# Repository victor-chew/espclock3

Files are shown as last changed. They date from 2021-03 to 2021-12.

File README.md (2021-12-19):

# ESPCLOCK3
Internet-enabled Analog Clock using ESP8266 and ATtiny85

### Description
This is version 3 of my [ESPClock](https://www.randseq.org/2016/10/hacking-analog-clock-to-sync-with-ntp.html) project.

The clock gets accurate time information from the Internet and makes sure the physical clock time is up-to-date. It also automatically detects your current timezone via browser geolocation and deals with daylight saving adjustments with no user intervention.

V1 uses the ESP-12E development board to drive a cheap $2 Ikea analog clock.

V2 uses the WeMOS D1 Mini and ATtiny85 to reduce power draw. That design yields a runtime of ~1 month.

V3 uses the ESP-07, ATtiny85 and PCF8563 RTC to reduce the power draw even further. This design yields at least 4 months of runtime on a set of readily-available 4 x 1.2V AA NiMH rechargables.

### Links:
* [Design](https://www.randseq.org/2020/05/espclock3-final-version.html)

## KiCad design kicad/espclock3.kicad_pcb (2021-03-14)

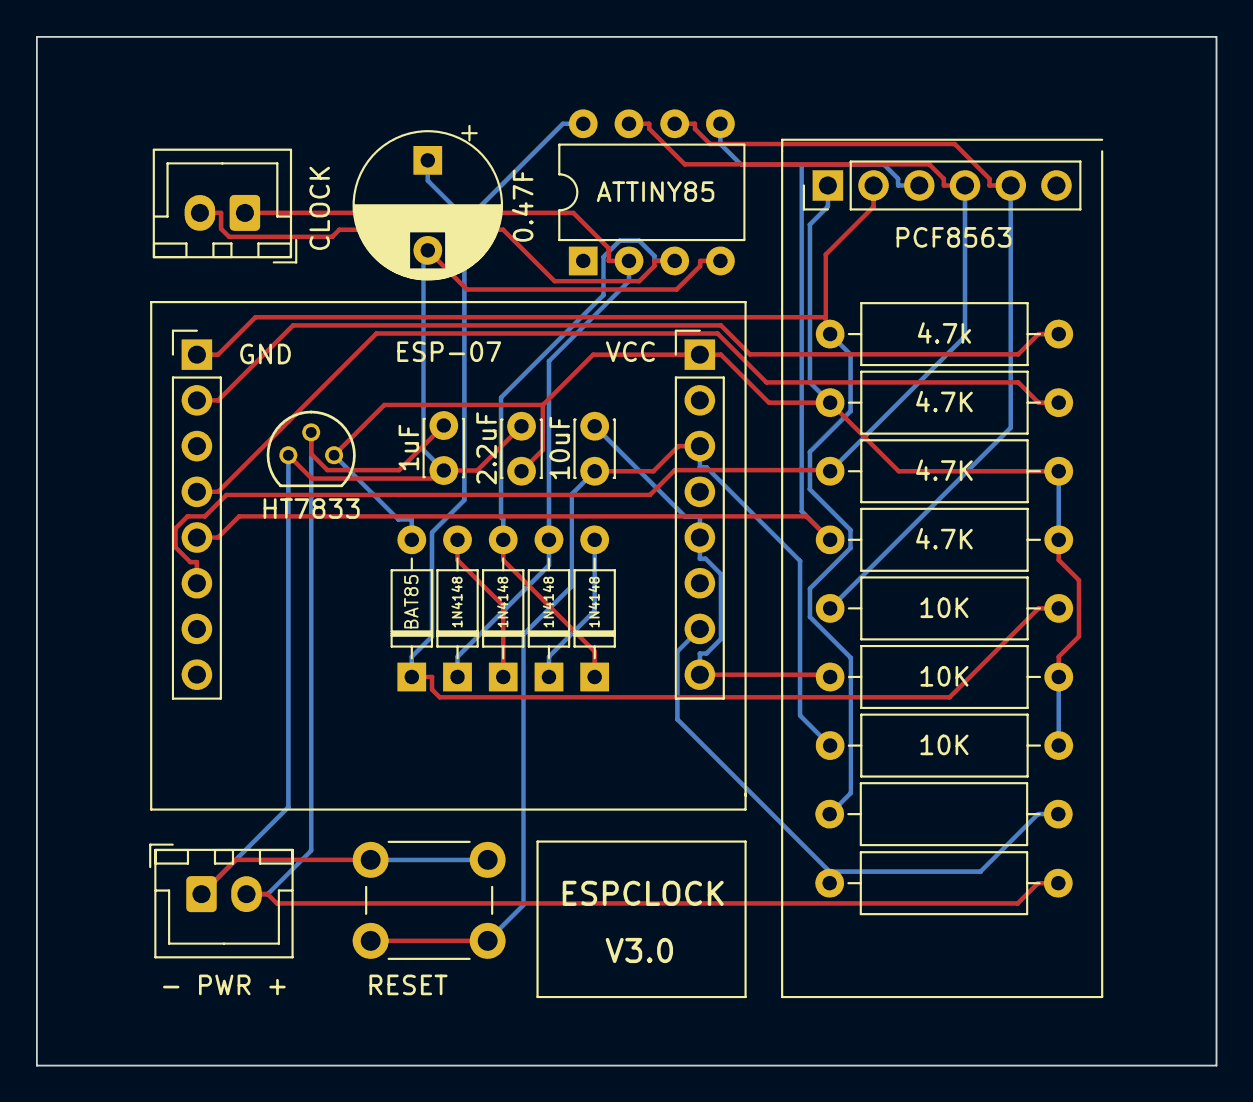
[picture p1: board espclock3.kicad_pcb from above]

Board: 2 copper layers, 65.5 x 57.2 mm, 26 parts (0 on the bottom side), 17 nets.

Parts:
C1: 1uF; C_Disc_D3.0mm_W2.0mm_P2.50mm
C2: 2.2uF; C_Disc_D3.0mm_W2.0mm_P2.50mm
C3: 10uF; C_Disc_D3.0mm_W2.0mm_P2.50mm
C4: 0.47F; CP_Radial_D8.0mm_P5.00mm
D1: BAT85; D_DO-35_SOD27_P7.62mm_Horizontal
D2, D3, D4, D5: 1N4148; D_DO-35_SOD27_P7.62mm_Horizontal
ESP07-GND1, ESP07-VCC1: Conn_01x08_Female; PinHeader_1x08_P2.54mm_Vertical
J1: Quartz Clock; JST_XH_B2B-XH-A_1x02_P2.50mm_Vertical
J2: Battery; JST_XH_B2B-XH-A_1x02_P2.50mm_Vertical
J5: PCF8563; PinHeader_1x06_P2.54mm_Vertical
L1: HT7833; ht7333-a
R1, R4, R7, R9: 10K; R_Axial_DIN0309_L9.0mm_D3.2mm_P12.70mm_Horizontal
R2: 4.7k; R_Axial_DIN0309_L9.0mm_D3.2mm_P12.70mm_Horizontal
R3, R5, R6: 4.7K; R_Axial_DIN0309_L9.0mm_D3.2mm_P12.70mm_Horizontal
R8: 47K; R_Axial_DIN0309_L9.0mm_D3.2mm_P12.70mm_Horizontal
SW1: SW_Push; SW_PUSH_6mm
U3: ATtiny85-20PU; DIP-8_W7.62mm

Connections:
/ADC: ESP07-VCC1.7, R8.1, R9.2
/COT: J5.5, R7.1, U3.6
/GND: ESP07-GND1.1, J5.2, R2.1, R9.1
/GPIO0: ESP07-GND1.4, R3.2
/GPIO12: C3.1, ESP07-VCC1.3, R4.1, SW1.2
/GPIO15: ESP07-GND1.2, R2.2
/GPIO16: C3.2, ESP07-VCC1.5, ESP07-VCC1.8, R1.1
/SCL: ESP07-GND1.6, J5.4, R5.1, U3.7
/SDA: ESP07-GND1.5, J5.3, R6.1, U3.5
/VCC: C2.1, D1.2, ESP07-VCC1.1, J5.1, L1.3, R1.2, R3.1, R4.2, R5.2, R6.2
unnamed: C1.1, J2.2, L1.2, R8.2
unnamed: C1.2, C2.2, C4.2, J2.1, L1.1, SW1.1, U3.4
unnamed: C4.1, D1.1, R7.2, U3.8
unnamed: D2.1, D3.2, J1.1, U3.2
unnamed: D2.2, D4.1
unnamed: D3.1, D5.2
unnamed: D4.2, D5.1, J1.2, U3.3

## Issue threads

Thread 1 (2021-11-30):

Question

bilogic, 2021-11-30:
Hi,

Cool project! How does your electronics figure out the hand positions? (And not lose track of them)

victor-chew, 2021-12-01:
You tell it the current hand position during setup, and it will keep track during movement of the hands. The tricky thing is to remember the hand position (by writing to EEPROM on the ATtiny85) when low power is detected.

bilogic, 2021-12-01:
Ah ok got it, thank you!
I would jump straight into this if it was more robust :)

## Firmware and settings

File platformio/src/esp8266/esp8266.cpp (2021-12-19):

/*
 * esp8266.cpp
 *
 * Copyright 2020 Victor Chew
 *
 * Licensed under the Apache License, Version 2.0 (the "License");
 * you may not use this file except in compliance with the License.
 * You may obtain a copy of the License at
 *
 *     http://www.apache.org/licenses/LICENSE-2.0
 *
 * Unless required by applicable law or agreed to in writing, software
 * distributed under the License is distributed on an "AS IS" BASIS,
 * WITHOUT WARRANTIES OR CONDITIONS OF ANY KIND, either express or implied.
 * See the License for the specific language governing permissions and
 * limitations under the License.
 */
 
#include <Arduino.h>
#include <stdint.h>
#include <LittleFS.h>
#include <ESP8266WiFi.h>
#include <DNSServer.h>
#include <ESP8266WebServer.h>
#include <WiFiManager.h>
#include <ESP8266HTTPClient.h>
#include <Rtc_Pcf8563.h> // https://github.com/elpaso/Rtc_Pcf8563

#define DEBUG
#ifdef DEBUG
#include <Syslog.h>
WiFiUDP udpClient;
Syslog syslog(udpClient, "192.168.1.167", 514, "ESPCLOCK3", "ESPCLOCK3", LOG_KERN);
#endif

void debug(const char *format, ...) {
  #ifdef DEBUG
    char buf[256];
    va_list ap;
    va_start(ap, format);
    vsnprintf(buf, sizeof(buf), format, ap);
    va_end(ap);
    syslog.log(buf);
  #endif
}

// Application Javascript to be injected into WiFiManager's config page
#define QUOTE(...) #__VA_ARGS__
const char* jscript = QUOTE(
  <script>
    document.addEventListener('DOMContentLoaded', tzinit, false); 
    function tzinit() {
      document.getElementById("timezone").value = Intl.DateTimeFormat().resolvedOptions().timeZone;
    }
  </script>
);

/*
 * PHP script can be hosted on your own server:
 *
 * <?php
 * if (isset($_REQUEST['tz'])) {
 *   $time = new DateTime();
 *   $time->setTimezone(new DateTimeZone($_REQUEST['tz']));
 *   print $time->format('h:i:s');
 * }
 * ?>
 *
 * Or you can use the version hosted at http://espclock.randseq.org/now.php
 *
 * List of timezones can be found here: https://en.wikipedia.org/wiki/List_of_tz_database_time_zones
 */

#define I2C_SLAVE_ADDR 0x12
#define CMD_START_CLOCK 0x2
#define CMD_STOP_CLOCK 0x4
#define CMD_SET_CLOCK 0x6
#define CMD_SET_NETTIME 0x8
#define CONFIG_PIN 12
#define DEFAULT_SCRIPT_URL "http://espclock.randseq.org/now.php?tz=[tz]"
#define CONFIG_FILE "espclock.ini"
#define STOP_VOLTAGE (1.05 * 4)

// Variables
bool shouldSaveConfig = false;
byte clockHH = 0, clockMM = 0, clockSS = 0, netHH = 0, netMM = 0, netSS = 0;
char param_tz[48] = "UTC", param_url[128] = DEFAULT_SCRIPT_URL;
char buf_timezone[48] = "", buf_clockTime[10] = "", buf_scriptUrl[128] = DEFAULT_SCRIPT_URL;
WiFiManagerParameter form_timezone("timezone", "TZ database timezone code", buf_timezone, sizeof(buf_timezone)-1);
WiFiManagerParameter form_clockTime("clockTime", "Time on clock (12-hr HHMMSS)", buf_clockTime, sizeof(buf_clockTime)-1);
WiFiManagerParameter form_scriptUrl("scriptUrl", "URL to ESPCLOCK script", buf_scriptUrl, sizeof(buf_scriptUrl)-1);
WiFiManager wifiManager;
Rtc_Pcf8563 rtc;

// Called by WiFiManager when there are config values to be saved
void saveConfigCallback () {
  shouldSaveConfig = true;
}

void readLine(File& file, char* buf, unsigned int bufsize) {
  unsigned int i = 0;
  while(file.available() && i < bufsize-1) {
    buf[i] = file.read();
    if (buf[i++] == '\n') break;
  }
  buf[i] = 0;
}

bool startsWith(const char* str, const char* head) {
  unsigned int i, len = min(strlen(str), strlen(head));
  for (i=0; i<len; i++) 
    if (str[i] != head[i]) return false;
  return i == strlen(head);
}

void setParam(char* param, unsigned int paramSize, char* buf) {
  memset((void*)param, 0, paramSize);
  char* ptr = buf; while(*ptr++ != '=');
  strncpy(param, ptr, paramSize-1);
}

// Read config parameters to flash
void loadConfig() {
  char buf[256];
  memset((void*)buf, 0, sizeof(buf));
  File file = LittleFS.open(CONFIG_FILE, "r");
  if (!file) return; 
  while(true) {
    readLine(file, buf, sizeof(buf));
    if (strlen(buf) == 0) break;
    if (startsWith(buf, "tz=")) setParam(param_tz, sizeof(param_tz), buf);
    else if (startsWith(buf, "url=")) setParam(param_url, sizeof(param_url), buf);
  }
  file.close();
}

// Write config parameters to flash
void saveConfig() {
  File file = LittleFS.open(CONFIG_FILE, "w");
  if (!file) return;
  file.write("tz="); file.write(param_tz, sizeof(param_tz)); file.write('\n');
  file.write("url="); file.write(param_url, sizeof(param_url)); file.write('\n');
  file.close();
}

bool getNetworkTime() {
  String url = param_url;
  String tz = param_tz;
  tz.replace("/", "%2F");
  url.replace("[tz]", tz);
  WiFiClient wifi;
  HTTPClient http;
  http.begin(wifi, url.c_str());
  int rc = http.GET();
  if (rc == HTTP_CODE_OK) {
    String payload = http.getString();
    if (payload.length() >= 8) {
      String hh = payload.substring(0, 2);
      String mm = payload.substring(3, 5);
      String ss = payload.substring(6, 8);
      netHH = hh.toInt();
      netMM = mm.toInt();
      netSS = ss.toInt();
      if (netHH >= 12) netHH -= 12;
      if (netHH < 0 || netHH > 23) netHH = 0;
      if (netMM < 0 || netMM > 59) netMM = 0;
      if (netSS < 0 || netSS > 59) netSS = 0;
      return true;
    }
  }
  return false;
}

void attinyStartClock() {
  Wire.beginTransmission(I2C_SLAVE_ADDR);
  byte start_clock[] = { CMD_START_CLOCK, 0xCC ^ CMD_START_CLOCK };
  Wire.write(start_clock, sizeof(start_clock));
  Wire.endTransmission();
  delay(100);
}

void attinyStopClock() {
  delay(200);
  Wire.beginTransmission(I2C_SLAVE_ADDR);
  byte stop_clock[] = { CMD_STOP_CLOCK, 0xCC ^ CMD_STOP_CLOCK };
  Wire.write(stop_clock, sizeof(stop_clock));
  Wire.endTransmission();
  delay(100);
}

void attinySetClock() {
  byte setclock[] = { CMD_SET_CLOCK, clockHH, clockMM, clockSS, 0xCC };
  for (unsigned int i=0; i<sizeof(setclock)-1; i++) setclock[sizeof(setclock)-1] ^= setclock[i];
  Wire.beginTransmission(I2C_SLAVE_ADDR);
  Wire.write(setclock, sizeof(setclock));
  Wire.endTransmission();
  delay(100);
}

void attinySetNetTime() {
  byte nettime[] = { CMD_SET_NETTIME, netHH, netMM, netSS, 0xCC };
  for (unsigned int i=0; i<sizeof(nettime)-1; i++) nettime[sizeof(nettime)-1] ^= nettime[i];
  Wire.beginTransmission(I2C_SLAVE_ADDR);
  Wire.write(nettime, sizeof(nettime));
  Wire.endTransmission();
  delay(100);
}

// This function returns immediately if WiFi connection is made successfully using previous credentials.
// Otherwise it waits until user enters correct credentials for WiFi connection, or timeout after 5 minutes and go into deep-sleep.
// Onboard blue LED of ESP-7 (GPIO2) is used to indicate device has started in AP mode and waiting for configuration.
void initAP() {
  wifiManager.setCustomHeadElement(jscript);
  wifiManager.addParameter(&form_clockTime);
  wifiManager.addParameter(&form_timezone);
  wifiManager.addParameter(&form_scriptUrl);
  wifiManager.setConfigPortalTimeout(5*60);
  pinMode(LED_BUILTIN, OUTPUT);
  digitalWrite(LED_BUILTIN, LOW); // Note: built-in LED is active low
  String clockName = String("ESPCLOCK3-") + ESP.getChipId();
  bool success = wifiManager.autoConnect(clockName.c_str());
  digitalWrite(LED_BUILTIN, HIGH);
  pinMode(LED_BUILTIN, INPUT_PULLUP);
  if (!success) ESP.deepSleep(2*60*60*1e6, WAKE_RF_DEFAULT);
}

// Parse config values entered in AP form
void parseConfig() {
  strncpy(param_tz, form_timezone.getValue(), sizeof(param_tz) - 1);
  strncpy(param_url, form_scriptUrl.getValue(), sizeof(param_url) - 1);
  int clockTime = atoi(form_clockTime.getValue());
  if (clockTime < 10000) clockTime *= 100;
  clockSS = clockTime % 100; if (clockSS >= 60) clockSS = 0;
  clockMM = (clockTime / 100) % 100; if (clockMM >= 60) clockMM = 0;
  clockHH = clockTime / 10000; while(clockHH >= 12) clockHH -= 12;
  attinySetClock();
}

/**
 * I2C_ClearBus
 * (http://www.forward.com.au/pfod/ArduinoProgramming/I2C_ClearBus/index.html)
 * (c)2014 Forward Computing and Control Pty. Ltd.
 * NSW Australia, www.forward.com.au
 * This code may be freely used for both private and commerical use
 */

/**
 * This routine turns off the I2C bus and clears it
 * on return SCA and SCL pins are tri-state inputs.
 * You need to call Wire.begin() after this to re-enable I2C
 * This routine does NOT use the Wire library at all.
 *
 * returns 0 if bus cleared
 *         1 if SCL held low.
 *         2 if SDA held low by slave clock stretch for > 2sec
 *         3 if SDA held low after 20 clocks.
 */
int I2C_ClearBus() {
#if defined(TWCR) && defined(TWEN)
  TWCR &= ~(_BV(TWEN)); // Disable the Atmel 2-Wire interface so we can control the SDA and SCL pins directly
#endif

  pinMode(SDA, INPUT_PULLUP); // Make SDA (data) and SCL (clock) pins Inputs with pullup.
  pinMode(SCL, INPUT_PULLUP);

  delay(2500);  // Wait 2.5 secs. This is strictly only necessary on the first power
  // up of the DS3231 module to allow it to initialize properly,
  // but is also assists in reliable programming of FioV3 boards as it gives the
  // IDE a chance to start uploaded the program
  // before existing sketch confuses the IDE by sending Serial data.

  boolean SCL_LOW = (digitalRead(SCL) == LOW); // Check is SCL is Low.
  if (SCL_LOW) { //If it is held low Arduno cannot become the I2C master. 
    return 1; //I2C bus error. Could not clear SCL clock line held low
  }

  boolean SDA_LOW = (digitalRead(SDA) == LOW);  // vi. Check SDA input.
  int clockCount = 20; // > 2x9 clock

  while (SDA_LOW && (clockCount > 0)) { //  vii. If SDA is Low,
    clockCount--;
  // Note: I2C bus is open collector so do NOT drive SCL or SDA high.
    pinMode(SCL, INPUT); // release SCL pullup so that when made output it will be LOW
    pinMode(SCL, OUTPUT); // then clock SCL Low
    delayMicroseconds(10); //  for >5uS
    pinMode(SCL, INPUT); // release SCL LOW
    pinMode(SCL, INPUT_PULLUP); // turn on pullup resistors again
    // do not force high as slave may be holding it low for clock stretching.
    delayMicroseconds(10); //  for >5uS
    // The >5uS is so that even the slowest I2C devices are handled.
    SCL_LOW = (digitalRead(SCL) == LOW); // Check if SCL is Low.
    int counter = 20;
    while (SCL_LOW && (counter > 0)) {  //  loop waiting for SCL to become High only wait 2sec.
      counter--;
      delay(100);
      SCL_LOW = (digitalRead(SCL) == LOW);
    }
    if (SCL_LOW) { // still low after 2 sec error
      return 2; // I2C bus error. Could not clear. SCL clock line held low by slave clock stretch for >2sec
    }
    SDA_LOW = (digitalRead(SDA) == LOW); //   and check SDA input again and loop
  }
  if (SDA_LOW) { // still low
    return 3; // I2C bus error. Could not clear. SDA data line held low
  }

  // else pull SDA line low for Start or Repeated Start
  pinMode(SDA, INPUT); // remove pullup.
  pinMode(SDA, OUTPUT);  // and then make it LOW i.e. send an I2C Start or Repeated start control.
  // When there is only one I2C master a Start or Repeat Start has the same function as a Stop and clears the bus.
  /// A Repeat Start is a Start occurring after a Start with no intervening Stop.
  delayMicroseconds(10); // wait >5uS
  pinMode(SDA, INPUT); // remove output low
  pinMode(SDA, INPUT_PULLUP); // and make SDA high i.e. send I2C STOP control.
  delayMicroseconds(10); // x. wait >5uS
  pinMode(SDA, INPUT); // and reset pins as tri-state inputs which is the default state on reset
  pinMode(SCL, INPUT);
  return 0; // all ok
}

float getSupplyVoltage() {
  int sum = 0;
  analogRead(A0);
  for (int i=0; i<8; i++) sum += analogRead(A0);
  sum = sum >> 3; // divide by 8
  float ratio = sum / 1024.0;
  return ratio * 57.0 / 10.0;
}

byte I2C_Scan() {
  int num = 0;
  byte addr[5] = { 0, 0, 0, 0, 0 };

  Wire.beginTransmission(0x12);
  byte error = Wire.endTransmission();
  if (error == 0) addr[num++] = 0x12;
  delay(100);

  Wire.beginTransmission(0x51);
  error = Wire.endTransmission();
  if (error == 0) addr[num++] = 0x51;
  delay(100);

  #ifdef DEBUG
  char msg[256];
  sprintf(msg, "I2C devices (%d)", num);
  if (num > 0) {
    strcat(msg, ": ");
    for (int i=0; i<num; i++) {
      char addstr[8] = "";
      sprintf(addstr, "%02X ", addr[i]);
      strcat(msg, addstr);
    }
  }
  debug(msg);
  #endif
  
  return num;
}

void setup() {
  // Reduce power drain
  WiFi.setOutputPower(0.0);

  // Load config from flash
  if (!LittleFS.begin()) ESP.deepSleep(0);
  loadConfig();

  // Setup I2C - SDA (GPIO4), SCL (GPIO5)
  Wire.begin();
  Wire.setClockStretchLimit(1500); // to accommodate for ATTiny85's slower speed at 1MHz

  // If reset detected, start in config mode
  delay(500); // Wait a little for debounce
  pinMode(CONFIG_PIN, INPUT_PULLUP);
  bool reset = !digitalRead(CONFIG_PIN);
  if (reset) attinyStopClock();

  // Start WiFiManager
  wifiManager.setSaveConfigCallback(saveConfigCallback);
  if (reset) wifiManager.resetSettings();
  initAP();

  // At this point, shouldSaveConfig will tell us whether WiFiManager has connected
  // using previously stored SSID/password, or new ones has been into the config portal
  // and should be saved to flash memory.
  if (shouldSaveConfig) {
    parseConfig();
    saveConfig();
  } 

  // Test I2C line. If total number of slaves is not 2 (RTC and ATtiny85), 
  // try to reset I2C bus and try again after 1 minute deep sleep.
  if (I2C_Scan() != 2) {
    I2C_ClearBus();
    delay(1000);
    ESP.deepSleep(5*60*1e6, WAKE_RF_DEFAULT);
    while(true);
  }
  
  // Freeze when supply voltage goes below threshold
  float supply = getSupplyVoltage();
  debug("Supply = %.2f", supply);
  if (supply <= STOP_VOLTAGE) {
    rtc.setSquareWave(SQW_DISABLE);
    delay(1000);
    ESP.deepSleep(0);
  }

  // Read ATtiny85 heartbeat
  byte hb[3] = { 0 };
  Wire.requestFrom(I2C_SLAVE_ADDR, sizeof(hb));
  int numbytes = Wire.readBytes(hb, sizeof(hb));
  syslog.logf(LOG_INFO, "Heartbeat: [%d] %02d:%02d:%02d", numbytes, hb[0], hb[1], hb[2]);

  // Enable 1HZ clock output signal on RTC
  rtc.setSquareWave(SQW_1HZ);

  // Tell ATtiny85 to start ticking and send it the current network time
  attinyStartClock(); 
  if (getNetworkTime()) attinySetNetTime();

  // 2 hour deep sleep
  delay(1000);
  ESP.deepSleep(2*60*60*1e6, WAKE_RF_DEFAULT);
}

void loop() {
  // When ESP8266 wakes up from deep sleep, setup() is called.
}

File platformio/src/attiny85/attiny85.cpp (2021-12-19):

/*
 * attiny85.cpp
 *
 * Copyright 2020 Victor Chew
 *
 * Licensed under the Apache License, Version 2.0 (the "License");
 * you may not use this file except in compliance with the License.
 * You may obtain a copy of the License at
 *
 *     http://www.apache.org/licenses/LICENSE-2.0
 *
 * Unle_SS required by applicable law or agreed to in writing, software
 * distributed under the License is distributed on an "AS IS" BASIS,
 * WITHOUT WARRANTIES OR CONDITIONS OF ANY KIND, either expre_SS or implied.
 * See the License for the specific language governing permi_SSions and
 * limitations under the License.
 */

#include <Arduino.h>
#include <Wire.h>
#include <limits.h>
#include <avr/io.h>
#include <avr/wdt.h>
#include <avr/sleep.h>
#include <avr/power.h>
#include <avr/interrupt.h>
#include <EEPROM.h>

#define _HH 0
#define _MM 1
#define _SS 2

#define I2C_SLAVE_ADDR 0x12
#define CMD_START_CLOCK 0x2
#define CMD_STOP_CLOCK 0x4
#define CMD_SET_CLOCK 0x6
#define CMD_SET_NETTIME 0x8

#define SQW_PIN PB1
#define PULSE_WIDTH 40

bool clock_running = false;
byte tickpin = PB3, prev_net_ss = 255;

// Variables used by ISRs must be marked as volatile
volatile bool check_hibernate = false;
volatile byte numticks = 0;
volatile byte clocktime[3] = {0}; // physical clock time
volatile byte nettime[3] = {0};   // network clock time
volatile byte msg[5] = {0};

// Function prototypes
static void incTime(volatile byte& hh, volatile byte& mm, volatile byte& ss);
static void processMessage();
static void enablePinChangeInterrupt(bool enable);
static void writeEEPROM();

// Triggers every ~8s to check whether we should save status and hibernate
ISR(WDT_vect) {
  check_hibernate = true;
}

// Pin change interrupt; respond to falling edge of 1Hz clock signal connected to PB1
ISR(PCINT0_vect) {
  if (digitalRead(SQW_PIN) == LOW) numticks += 1;
}

// Process messages from master
void receiveEvent(int numbytes) {
  if (numbytes > (int)sizeof(msg)) return; // Sanity check
  int idx = 0;
  while(idx < numbytes) {
    if (Wire.available()) msg[idx++] = Wire.read();
  }
  byte checksum = 0xCC;
  for (int i=0; i<numbytes-1; i++) checksum ^= msg[i];
  if (checksum == msg[numbytes-1]) processMessage();
}  

void processMessage() {
  switch(msg[0]) {
    case CMD_START_CLOCK:
      clock_running = true;
      prev_net_ss = 255;
      enablePinChangeInterrupt(true);
      break;
    case CMD_STOP_CLOCK:
      clock_running = false;
      enablePinChangeInterrupt(false);
      writeEEPROM();
      break;
    case CMD_SET_CLOCK:
      memcpy(clocktime, (void*)(msg+1), sizeof(clocktime));
      memcpy((void*)nettime, clocktime, sizeof(nettime));
      break;
    case CMD_SET_NETTIME:
      memcpy((void*)nettime, (void*)(msg+1), sizeof(nettime));
      break;
  }
}

void enablePinChangeInterrupt(bool enable) {
  if (enable) GIMSK |= bit(PCIE); 
  else GIMSK &= ~bit(PCIE);
}

void incTime(volatile byte& hh, volatile byte& mm, volatile byte& ss) {
  if (++ss >= 60) {
    ss = 0;
    if (++mm >= 60) {
      mm = 0;
      if (++hh >= 12) {
        hh = 0;
      }
    }
  }
}

// Move second hand one tick clockwise.
// See: http://www.cibomahto.com/2008/03/controlling-a-clock-with-an-arduino/
void incSecondHand() {
  incTime(clocktime[_HH], clocktime[_MM], clocktime[_SS]);
  digitalWrite(tickpin, HIGH);
  delay(PULSE_WIDTH);
  digitalWrite(tickpin, LOW);
  tickpin = (tickpin == PB3) ? PB4 : PB3;
}

// Pulse the same pin, which will cause the second hand to vibrate but not advance.
// This lets the user know the clock is waiting for network time to catch up.
void pulseSecondHand() {
  digitalWrite(tickpin, HIGH);
  delay(PULSE_WIDTH);
  digitalWrite(tickpin, LOW);
}

// If clock time != network time, adjust until they match (returns false)
// Otherwise put MCU to sleep (returns true).
bool synchronizeClock() {
  // Calculate time difference between physical clock and network time in seconds
  long diff = ((clocktime[_HH] * 3600L) + (clocktime[_MM] * 60L) + clocktime[_SS]) -
              ((nettime[_HH] * 3600L) + (nettime[_MM] * 60L) + nettime[_SS]);
  if (diff == 0) return true;
  if (diff < 0) diff = (12L*60*60) + diff;

  // If clock time is ahead about 5 mins, pulse second hand and wait for network time to catch up
  if (diff <= 5*60) {
    pulseSecondHand();
    return true;
  }

  // Otherwise, fast-forward clock and try to catch up
  incSecondHand();
  if (memcmp(clocktime, (const void*)nettime, sizeof(clocktime)) == 0) return true;

  // Additional delay between clock ticks during fast-forwarding to prevent slippage
  delay(PULSE_WIDTH*2);
  return false;
}

// EEPROM: _HH MM _SS TICKPIN CHECKSUM
// CHECKSUM = 0xCC ^ _HH ^ MM ^ _SS ^ TICKPIN
void readEEPROM() {
  byte checksum = 0xCC, buf[4];
  for (unsigned int i=0; i<sizeof(buf); i++) {
    buf[i] = EEPROM.read(i);
    checksum ^= buf[i];
  }
  byte checksum2 = EEPROM.read(sizeof(buf));

  // Good checksum; use values in EEPROM
  if (checksum == checksum2) {
    memcpy(clocktime, buf, sizeof(clocktime));
    memcpy((void*)nettime, buf, sizeof(nettime));
    tickpin = buf[3];
  } 
  // Bad checksum; use default values
  else {
    memset(clocktime, 0, sizeof(clocktime));
    memset((void*)nettime, 0, sizeof(nettime));
    tickpin = PB3;
  }
}

void writeEEPROM() {
  byte checksum = 0xCC ^ clocktime[_HH] ^ clocktime[_MM] ^ clocktime[_SS] ^ tickpin;
  byte buf[] = { clocktime[_HH], clocktime[_MM], clocktime[_SS], tickpin, checksum }; 
  for (unsigned int i=0; i<sizeof(buf); i++) EEPROM.write(i, buf[i]);
}

void requestEvent() {
  for (int i=0; i<3; i++) Wire.write(clocktime[i]);
}

void setup() {
  // Initialization
  pinMode(SQW_PIN, INPUT_PULLUP);

  // Turn off ADC to save power during sleep
  ADCSRA &= ~bit(ADEN);
  power_adc_disable(); 
  set_sleep_mode(SLEEP_MODE_PWR_DOWN);
  sleep_enable();

  // Read existing config values from EEPROM
  readEEPROM();

  cli();

  // Setup as I2C slave
  Wire.begin(I2C_SLAVE_ADDR);
  Wire.onReceive(receiveEvent);
  Wire.onRequest(requestEvent);

  // Enable pin change interrupt for PCINT1 (PB6) to process clock signal from RTC
  // Global pin change interrupt will be enabled when clock is started
  PCMSK |= (1 << PCINT1);

  // Watchdog timer triggers every 8s to check if we should hibernate
  MCUSR &= ~bit(WDRF);
  WDTCR |= bit(WDCE) | bit(WDE);
  WDTCR = bit(WDIE) | bit(WDP3) | bit(WDP0);

  sei();
}
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

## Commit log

2021-03-14 Updated to v3.1
    Updated to v3.1
    [espclock3.dsn, espclock3.kicad_pcb]
2021-03-17 Added .gitignore for kicad folder
